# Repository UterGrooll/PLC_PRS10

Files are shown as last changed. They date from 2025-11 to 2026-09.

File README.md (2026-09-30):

# PLC_PRS10

ПЛК ПРС-10 на Arduino + Ethernet. Использую для своих задач в Rapid SCADA: два реле, местный датчик DS18B20 и четыре дискретных входа.

Обмен — `Modbus TCP Slave`, библиотека [ModbusTCP_RU](https://github.com/UterGrooll/ModbusTCP_RU) `0.3.0`, Ethernet `W5100/W5500`.

Фото устройства

## Возможности

- Управление двумя реле из SCADA.
- Автоматическое отключение первого реле через 60 секунд.
- Чтение температуры DS18B20 с точностью передачи 0,1 °C.
- Четыре дискретных входа с антидребезгом 50 мс.
- Восстановление Modbus-сервера после возврата Ethernet-линка W5500.

## Аппаратная часть

| Узел | Пин Arduino |
| --- | --- |
| Реле 1 | D7 |
| Реле 2 | D6 |
| DI1 | D2 |
| DI2 | D3 |
| DI3 | D4 |
| DI4 | D5 |
| DS18B20 | D9 |
| W5100/W5500 CS | D10 |

Реле включаются уровнем `HIGH`, при запуске оба выключены (`LOW`). Входы работают через `INPUT_PULLUP`: замкнутый на GND контакт — активный вход.

Ethernet использует стандартные пины SPI платы.

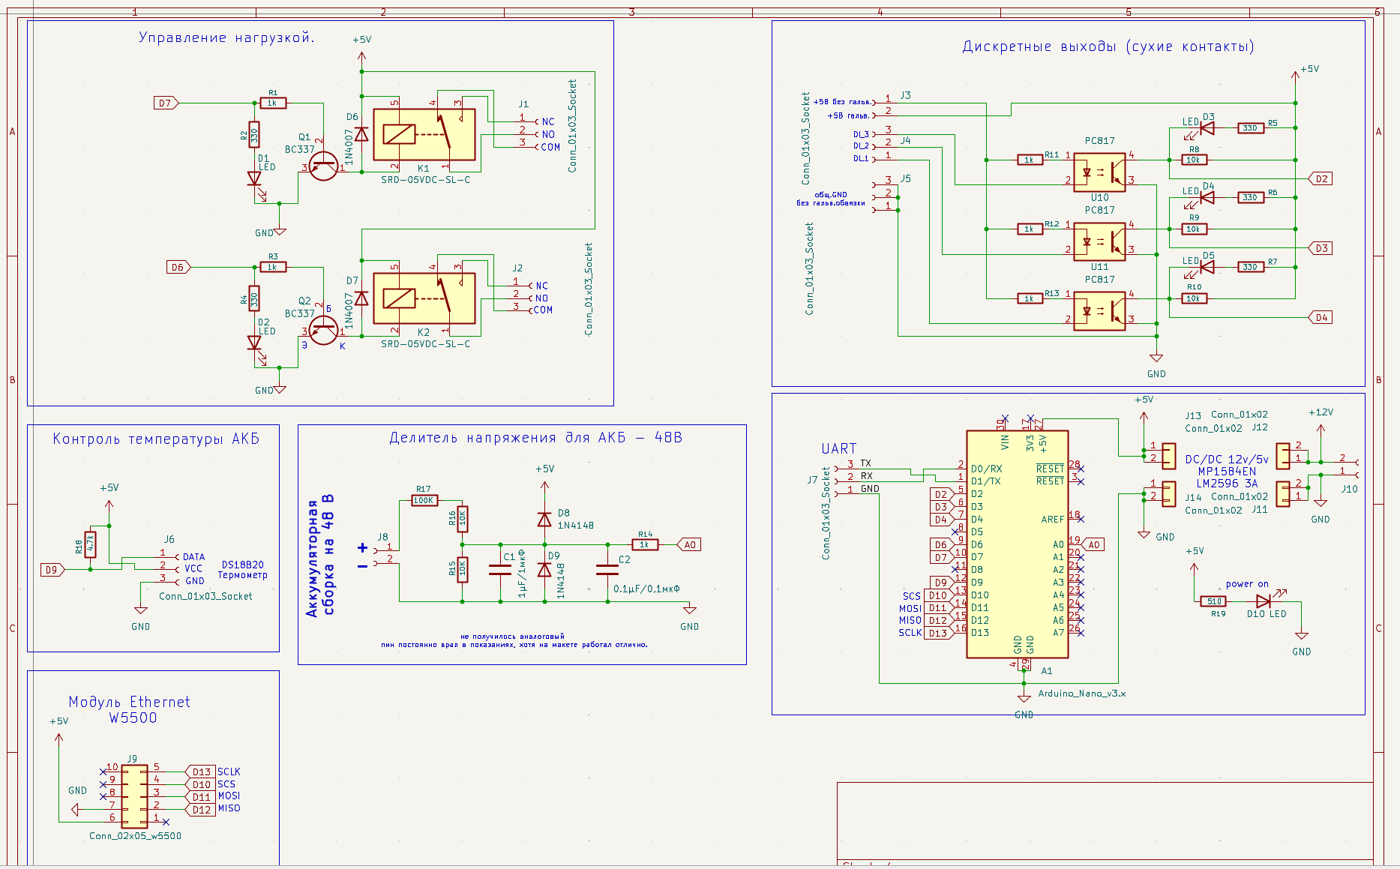
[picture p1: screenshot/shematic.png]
Схема


## Сеть

| Параметр | Значение |
| --- | --- |
| IP | `192.168.1.179` |
| MAC | `02:47:A1:10:00:02` |
| Шлюз / DNS | `192.168.1.1` |
| Маска | `255.255.255.0` |
| Порт Modbus TCP | `502` |

Для проверки нужен доступ к сети `192.168.1.0/24`. При необходимости сетевые параметры меняются в начале скетча. MAC и IP не должны совпадать с другим устройством в сети.

## Карта Modbus

Адреса в таблице начинаются с нуля. Coils, Discrete Inputs и Input Registers — отдельные области памяти.

| Область | FC | Address | Назначение |
| --- | --- | --- | --- |
| Coil | 01 / 05 / 15 | 0 | Реле 1, D7; авто-отключение через 60 с |
| Coil | 01 / 05 / 15 | 1 | Реле 2, D6 |
| Discrete Input | 02 | 0 | DI1, D2 |
| Discrete Input | 02 | 1 | DI2, D3 |
| Discrete Input | 02 | 2 | DI3, D4 |
| Discrete Input | 02 | 3 | DI4, D5 |
| Input Register | 04 | 0 | Местная температура DS18B20, °C × 10 |

Для реле: `0 = OFF`, `1 = ON`. Повторная команда ON не продлевает таймер реле 1; для нового цикла нужны OFF → ON. Время задаётся константой `RELAY1_TIMEOUT` в скетче. Настройки времени через Holding Registers здесь нет.

Для входов: `1 = замкнут / LOW`, `0 = разомкнут / HIGH`.

Температура передаётся как **Signed 16-bit**: `253 = 25,3 °C`, `-55 = -5,5 °C`. Значение `32767` означает ошибку или отсутствие измерения; его нельзя пересчитывать в температуру.

## Настройка Modbus Poll

Connection → Connect:

| Параметр | Значение |
| --- | --- |
| Connection | Modbus TCP/IP |
| IP | `192.168.1.179` |
| Server Port | `502` |
| Slave ID | `1` |
| Response Timeout | `1000 ms` |

Read/Write Definition:

| Что читать | Function | Address | Quantity |
| --- | --- | --- | --- |
| Реле | 01 Read Coils | 0 | 2 |
| Входы | 02 Read Discrete Inputs | 0 | 4 |
| Температура | 04 Read Input Registers | 0 | 1 |

Scan Rate для начала — `1000 ms`. При вводе этих адресов отключить `PLC Addresses (Base 1)`.

Запись реле выполняется через `05 Write Single Coil`: Address `0` для первого реле или `1` для второго, Value `ON/OFF`. Команду записи отправлять однократно.

Для температуры выбрать Signed 16-bit и делить значение на 10 в SCADA.

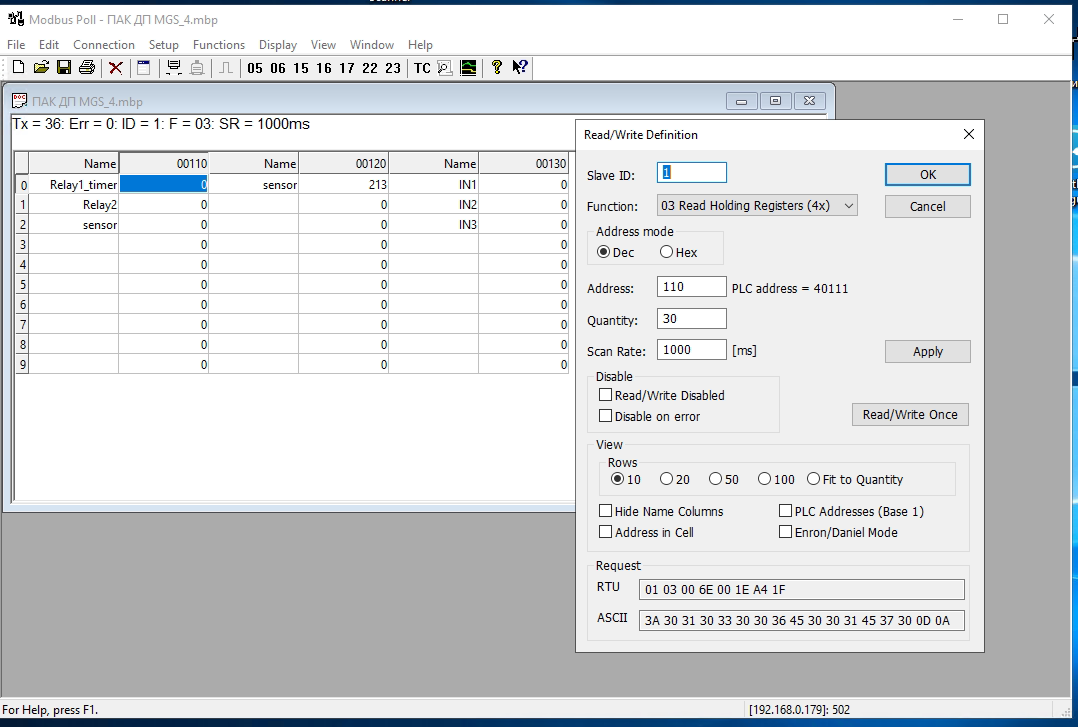
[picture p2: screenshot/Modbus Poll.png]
Modbus Poll


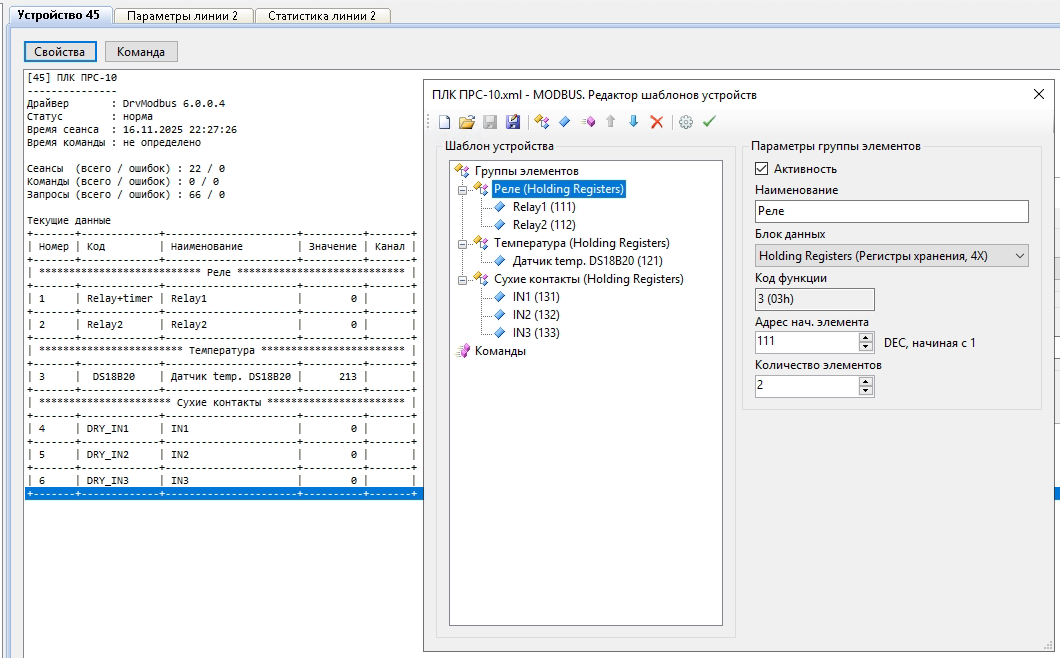
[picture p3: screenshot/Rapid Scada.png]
Rapid SCADA


## Восстановление Ethernet

При старте вызываются `Ethernet.begin(mac, ip, dnsServer, gateway, subnet)` и `mb.begin()`.

После пропадания и устойчивого возврата `LinkON` на W5500 выдерживается не менее 1,5 с, затем `mb.restart()` закрывает старые клиентские соединения. Повторного `Ethernet.begin()` и блокирующей паузы в этом обработчике нет. SCADA или Modbus Poll должны подключиться заново.

W5100 может возвращать `Unknown` в `linkStatus()`. Это не вызывает периодического сброса Ethernet.

Это контроль Ethernet-соединения, **не аппаратный watchdog AVR**. Аппаратный watchdog в этом скетче не включён.

## Прошивка

Актуальный скетч: [firmware/plc_prs10/plc_prs10.ino](firmware/plc_prs10/plc_prs10.ino).

Зависимости:

- `SPI` — входит в Arduino core.
- `Ethernet 2.0.2`.
- [ModbusTCP_RU 0.3.0](https://github.com/UterGrooll/ModbusTCP_RU).
- `GyverDS18`.

Размеры памяти Modbus задаются в общем файле библиотеки `src/ModbusTCP_RU_config.h`, а не через локальные `#define` в скетче.

Скетч собран для Arduino UNO и Nano ATmega328P Old Bootloader: `16820` байт Flash, `771` байт SRAM. Проверка сборки не заменяет испытания этой версии на плате.

После заливки проверить реле, четыре входа, температуру, авто-отключение реле 1 и переподключение после возврата кабеля. Реле проверять на безопасной нагрузке.

## Материалы

- [schematic/](schematic/) — исходники схемы.
- [case/](case/) — модель корпуса.
- [screenshot/](screenshot/) — фотографии и изображения.
- [src/](src/) — предыдущие скетчи; для текущей заливки используется только `firmware/plc_prs10/`.

---

by UterGrooll
2026

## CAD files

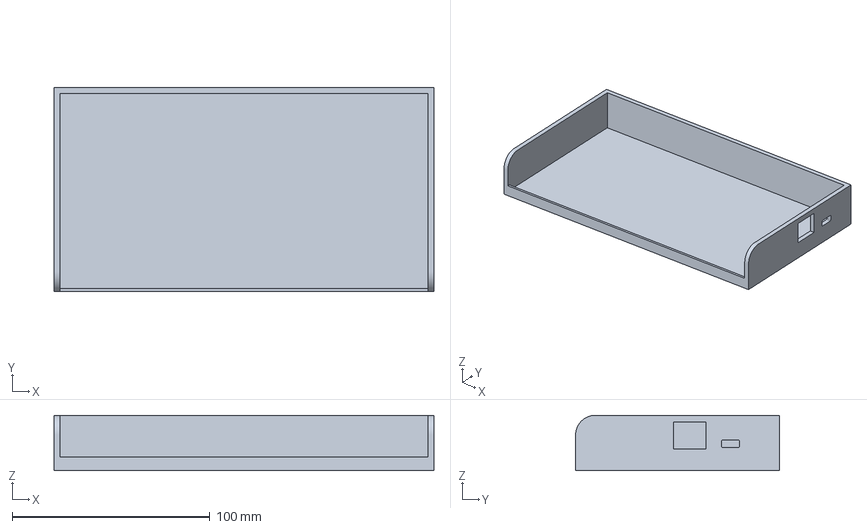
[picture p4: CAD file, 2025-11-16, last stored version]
case/case-Body.3mf
192.0 x 103.0 x 28.0 mm

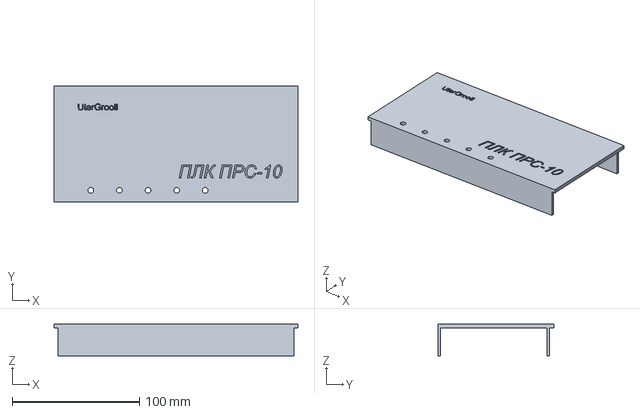
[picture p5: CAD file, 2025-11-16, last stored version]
case/case-ТелоPocket004.3mf
192.0 x 91.0 x 25.0 mm

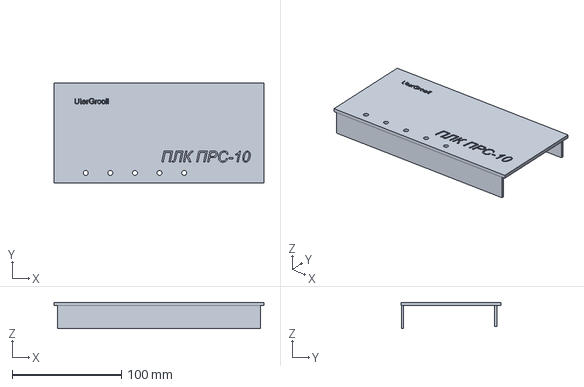
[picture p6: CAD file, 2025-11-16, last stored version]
case/case.FCStd
192.0 x 91.0 x 24.0 mm

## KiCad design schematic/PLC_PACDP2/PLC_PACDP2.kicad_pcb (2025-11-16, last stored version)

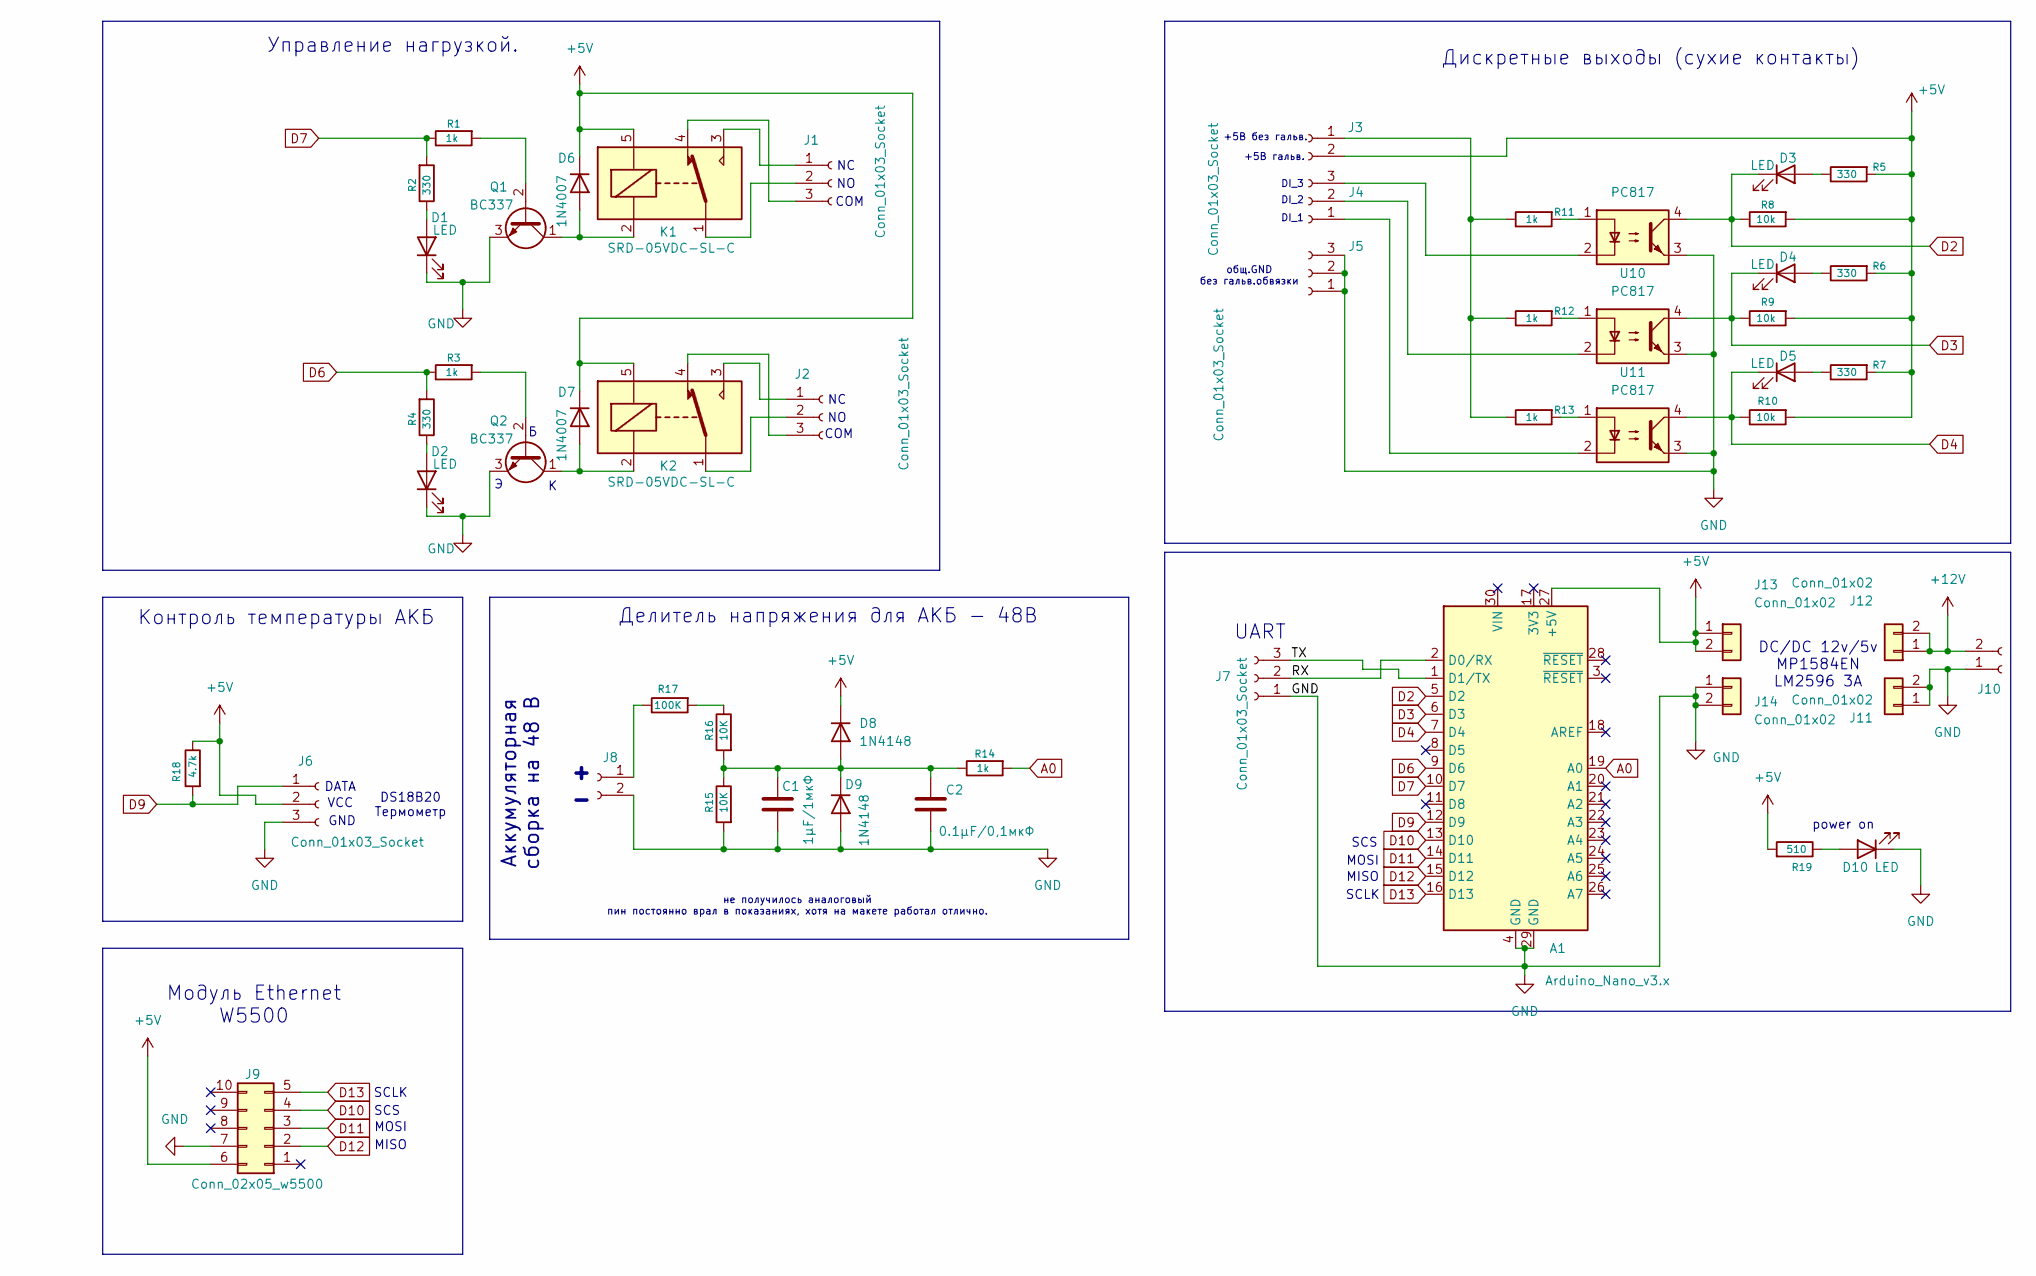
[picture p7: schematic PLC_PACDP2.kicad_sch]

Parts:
A1: Arduino_Nano_v3.x; Arduino_Nano
C1: 1µF/1мкФ; C_Rect_L4.6mm_W2.0mm_P2.50mm_MKS02_FKP02
C2: 0.1µF/0,1мкФ; C_Disc_D7.5mm_W2.5mm_P5.00mm
D1, D2, D3, D4, D5, D10: LED; LED_D5.0mm_Clear
D6, D7: 1N4007; D_DO-41_SOD81_P10.16mm_Horizontal
D8, D9: 1N4148; D_DO-35_SOD27_P7.62mm_Horizontal
J1, J2, J4, J5, J6: Conn_01x03_Socket; TerminalBlock_Phoenix_MKDS-1,5-3-5.08_1x03_P5.08mm_Horizont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
J3, J10: Conn_01x02_Socket; TerminalBlock_Phoenix_MKDS-1,5-2-5.08_1x02_P5.08mm_Horizont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; PartNumber KLS2-128-5.00-02P-4S
J7: Conn_01x03_Socket; PinSocket_1x03_P2.54mm_Vertical
J8: Conn_01x02_Socket; TerminalBlock_MetzConnect_Type703_RT10N02HGLU_1x02_P9.52mm_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; PartNumber KLS2-128-5.00-02P-4S
J9: Conn_02x05_w5500; PinSocket_2x05_P2.54mm_Vertical
J11, J12, J13, J14: Conn_01x02; PinSocket_1x02_P2.54mm_Vertical
K1, K2: SRD-05VDC-SL-C; Relay_SPDT_SANYOU_SRD_Series_Form_C
Q1, Q2: BC337; TO-92_Inline
R1, R3, R11, R12, R13, R14: 1k; R_Axial_DIN0207_L6.3mm_D2.5mm_P10.16mm_Horizontal; PartNumber RC0805FR-07510RL
R2, R4, R5, R6, R7: 330; R_Axial_DIN0207_L6.3mm_D2.5mm_P10.16mm_Horizontal; PartNumber RC0805FR-07510RL
R8, R9, R10: 10k; R_Axial_DIN0207_L6.3mm_D2.5mm_P10.16mm_Horizontal; PartNumber RC0805FR-07510RL
R15, R16: 10K; R_Axial_DIN0207_L6.3mm_D2.5mm_P10.16mm_Horizontal; PartNumber RC0805FR-07510RL
R17: 100K; R_Axial_DIN0207_L6.3mm_D2.5mm_P10.16mm_Horizontal; PartNumber RC0805FR-07510RL
R18: 4.7k; R_Axial_DIN0207_L6.3mm_D2.5mm_P10.16mm_Horizontal; PartNumber RC0805FR-07510RL
R19: 510; R_Axial_DIN0207_L6.3mm_D2.5mm_P10.16mm_Horizontal; PartNumber RC0805FR-07510RL
U9, U10, U11: PC817; DIP-4_W7.62mm

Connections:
+5V: A1.27 (+5V), D6.1 (K), D7.1 (K), D8.1 (K), J3.2, J6.2, J9.6 (+5), J13.1, J13.2, K1.5, K2.5, R5.2, R6.2, R7.2, R8.2, R9.2, R10.2, R18.1, R19.2
+12V: J10.2, J12.1, J12.2
/RX: A1.2 (D0/RX), J7.2
/TX: A1.1 (D1/TX), J7.3
D2: A1.5 (D2), D3.1 (K), R8.1, U9.4
D3: A1.6 (D3), D4.1 (K), R9.1, U10.4
D4: A1.7 (D4), D5.1 (K), R10.1, U11.4
D6: A1.9 (D6), R3.1, R4.2
D7: A1.10 (D7), R1.1, R2.2
D9: A1.12 (D9), J6.1, R18.2
D10: A1.13 (D10), J9.4 (SCS)
D11: A1.14 (D11), J9.3 (MOSI)
D12: A1.15 (D12), J9.2 (MISO)
D13: A1.16 (D13), J9.5 (SCLK)
GND: A1.4 (GND), A1.29 (GND), C1.2, C2.2, D1.1 (K), D2.1 (K), D9.2 (A), D10.1 (K), J5.1, J5.2, J5.3, J6.3, J7.1, J8.2, J9.7 (GND), J10.1, J11.1, J11.2, J14.1, J14.2, Q1.3 (E), Q2.3 (E), R15.2, U9.3, U10.3, U11.3
unnamed: D1.2 (A), R2.1
unnamed: D2.2 (A), R4.1
unnamed: D3.2 (A), R5.1
unnamed: D4.2 (A), R6.1
unnamed: D5.2 (A), R7.1
unnamed: D6.2 (A), K1.2, Q1.1 (C)
unnamed: D7.2 (A), K2.2, Q2.1 (C)
unnamed: C1.1, C2.1, D8.2 (A), D9.1 (K), R14.1, R15.1, R16.2
unnamed: D10.2 (A), R19.1
unnamed: J1.1, K1.3
unnamed: J1.2, K1.1
unnamed: J1.3, K1.4
unnamed: J2.1, K2.3
unnamed: J2.2, K2.1
unnamed: J2.3, K2.4
unnamed: J3.1, R11.1, R12.1, R13.1
unnamed: J4.1, U11.2
unnamed: J4.2, U10.2
unnamed: J4.3, U9.2
unnamed: J8.1, R17.1
unnamed: Q1.2 (B), R1.2
unnamed: Q2.2 (B), R3.2
unnamed: R11.2, U9.1
unnamed: R12.2, U10.1
unnamed: R13.2, U11.1
unnamed: R16.1, R17.2
А0: A1.19 (A0), R14.2

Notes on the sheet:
Управление нагрузкой.
SCS
DI_3
DI_2
Аккумуляторная сборка на 48 В
Модуль Ethernet W5500
COM
UART
SCLK
DS18B20 Термометр
DATA
MOSI
VCC
Контроль температуры АКБ
GND
MISO
общ.GND без гальв.обвязки
+5В гальв.
DC/DC 12v/5v MP1584EN LM2596 3A
DI_1
+5В без гальв.
power on
не получилось аналоговый пин постоянно врал в показаниях, хотя на макете работал отлично.
Дискретные выходы (сухие контакты)
Делитель напряжения для АКБ - 48В

Board: 2 copper layers, 53 parts (0 on the bottom side), 42 nets, no tracks yet.

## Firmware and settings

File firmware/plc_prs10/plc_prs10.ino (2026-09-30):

#include <SPI.h>
#include <Ethernet.h>
#include "ModbusTCP_RU.h"
#include <GyverDS18.h>

/* ---------- Network & Modbus ---------- */
byte mac[] = {0x02, 0x47, 0xA1, 0x10, 0x00, 0x02};
IPAddress ip(192, 168, 1, 179);
IPAddress gateway(192, 168, 1, 1);
IPAddress dnsServer(192, 168, 1, 1);
IPAddress subnet(255, 255, 255, 0);

ModbusTCP_RU mb;

/* ---------- Relays: Coils, FC01/FC05/FC15 ---------- */
const uint8_t RELAY1_PIN = 7;
const uint8_t RELAY2_PIN = 6;

const word COIL_RELAY1 = 0;
const word COIL_RELAY2 = 1;

const uint32_t RELAY1_TIMEOUT = 60000UL;  // 1 min
uint32_t relay1OnTime = 0;
bool relay1Active = false;

/* ---------- Temperature: Input Register, FC04 ---------- */
const uint8_t DS_PIN = 9;
GyverDS18Single ds(DS_PIN);

const word IREG_TEMP_X10 = 0;  // temperature * 10
const int16_t TEMP_ERROR_X10 = 32767;  // invalid/unavailable, not a temperature
const uint32_t TEMP_PERIOD_MS = 1000UL;  // >= 750 ms conversion at 12 bits
uint32_t temperatureRequestTime = 0;
bool temperatureConversionPending = false;

/* ---------- Inputs: Discrete Inputs, FC02 ---------- */
const uint8_t IN_PINS[] = { 2, 3, 4, 5 };
const uint8_t INPUT_COUNT = sizeof(IN_PINS) / sizeof(IN_PINS[0]);

const word DISC_INPUT_BASE = 0;

const uint32_t DEBOUNCE_MS = 50;
uint8_t inputState = 0;
uint8_t inputLast = 0;
uint32_t debounceTimer = 0;

/* ---------- Ethernet watchdog ---------- */
const uint32_t LINK_CHECK_PERIOD_MS = 1000UL;
const uint32_t LINK_RECOVER_DELAY_MS = 1500UL;

uint32_t linkCheckTimer = 0;
uint32_t linkUpTime = 0;
bool linkWasDown = false;
bool linkRecovering = false;

static_assert(MB_MAX_COILS > COIL_RELAY2, "Coil map is too small");
static_assert(MB_MAX_DISCRETE >= DISC_INPUT_BASE + INPUT_COUNT, "Discrete map is too small");
static_assert(MB_MAX_INPUT > IREG_TEMP_X10, "Input register map is too small");

void startEthernet()
{
  Ethernet.begin(mac, ip, dnsServer, gateway, subnet);
  mb.begin();
}

void updateEthernetWatchdog()
{
  uint32_t now = millis();

  if (now - linkCheckTimer < LINK_CHECK_PERIOD_MS) {
    return;
  }
  linkCheckTimer = now;

  EthernetLinkStatus link = Ethernet.linkStatus();

  if (link == LinkOFF) {
    linkWasDown = true;
    linkRecovering = false;
    return;
  }

  // W5100 reports Unknown; do not periodically reset an otherwise working chip.
  if (link == Unknown) {
    linkRecovering = false;
    return;
  }

  if (link == LinkON && linkWasDown) {
    if (!linkRecovering) {
      linkRecovering = true;
      linkUpTime = now;
    }
    if (now - linkUpTime >= LINK_RECOVER_DELAY_MS) {
      linkWasDown = false;
      linkRecovering = false;
      mb.restart();
    }
  }
}

void applyRelay(word address, bool value)
{
  switch (address) {
    case COIL_RELAY1:
      // Repeated SCADA writes must not postpone automatic shutdown.
      if (value && !relay1Active) {
        relay1OnTime = millis();
      } else if (!value) {
        relay1OnTime = 0;
      }
      relay1Active = value;
      digitalWrite(RELAY1_PIN, value ? HIGH : LOW);
      break;

    case COIL_RELAY2:
      digitalWrite(RELAY2_PIN, value ? HIGH : LOW);
      break;
  }
}

uint8_t readInputsRaw()
{
  uint8_t value = 0;

  for (uint8_t i = 0; i < INPUT_COUNT; i++) {
    if (digitalRead(IN_PINS[i]) == LOW) {
      value |= (1 << i);
    }
  }

  return value;
}

void updateInputs(uint32_t now)
{
  uint8_t nowInputs = readInputsRaw();

  if (nowInputs != inputLast) {
    inputLast = nowInputs;
    debounceTimer = now;
    return;
  }

  if ((now - debounceTimer) >= DEBOUNCE_MS && nowInputs != inputState) {
    inputState = nowInputs;

    for (uint8_t i = 0; i < INPUT_COUNT; i++) {
      mb.Discrete(DISC_INPUT_BASE + i, (inputState >> i) & 1);
    }
  }
}

void updateRelayTimer(uint32_t now)
{
  if (relay1Active && (uint32_t)(now - relay1OnTime) >= RELAY1_TIMEOUT) {
    mb.setCoilLocal(COIL_RELAY1, false);
    applyRelay(COIL_RELAY1, false);
  }
}

void startTemperatureConversion()
{
  temperatureConversionPending = ds.requestTemp();
  temperatureRequestTime = millis();
  if (!temperatureConversionPending) {
    mb.Ireg(IREG_TEMP_X10, (word)TEMP_ERROR_X10);
  }
}

void updateTemperature()
{
  // Independent timer: a failed request must not prevent the next retry.
  if ((uint32_t)(millis() - temperatureRequestTime) < TEMP_PERIOD_MS) {
    return;
  }

  if (temperatureConversionPending && ds.readTemp()) {
    float temperature = ds.getTemp();
    int16_t tempX10 = (int16_t)(temperature * 10.0f);
    mb.Ireg(IREG_TEMP_X10, (word)tempX10);
  } else {
    mb.Ireg(IREG_TEMP_X10, (word)TEMP_ERROR_X10);
  }

  startTemperatureConversion();
}

void setup()
{
  pinMode(RELAY1_PIN, OUTPUT);
  pinMode(RELAY2_PIN, OUTPUT);

  digitalWrite(RELAY1_PIN, LOW);
  digitalWrite(RELAY2_PIN, LOW);

  mb.setCoilLocal(COIL_RELAY1, false);
  mb.setCoilLocal(COIL_RELAY2, false);
  mb.Ireg(IREG_TEMP_X10, (word)TEMP_ERROR_X10);

  for (uint8_t i = 0; i < INPUT_COUNT; i++) {
    pinMode(IN_PINS[i], INPUT_PULLUP);
    mb.Discrete(DISC_INPUT_BASE + i, false);
  }

  inputState = readInputsRaw();
  inputLast = inputState;

  for (uint8_t i = 0; i < INPUT_COUNT; i++) {
    mb.Discrete(DISC_INPUT_BASE + i, (inputState >> i) & 1);
  }

  mb.onCoilWrite(applyRelay);

  Ethernet.init(10);
  startEthernet();

  startTemperatureConversion();
}

void loop()
{
  mb.MbsRun();

  uint32_t now = millis();
  updateRelayTimer(now);
  updateEthernetWatchdog();
  updateTemperature();
  updateInputs(now);
}

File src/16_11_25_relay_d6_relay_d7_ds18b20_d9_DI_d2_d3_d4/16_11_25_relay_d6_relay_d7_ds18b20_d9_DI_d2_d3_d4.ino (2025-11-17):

#include <SPI.h>
#include <Ethernet.h>
#include <ModbusEthernet.h>
#include <GyverDS18.h>

/* ---------- Network & Modbus ---------- */
byte mac[] = { 0xDE, 0xDD, 0xBE, 0xEF, 0xFE, 0x01 };
IPAddress ip(192, 168, 0, 179);
ModbusEthernet mb;

/* ---------- Relays ---------- */
const uint8_t RELAY1_PIN = 7;
const uint8_t RELAY2_PIN = 6;
const uint16_t REG_RELAY1 = 110;
const uint16_t REG_RELAY2 = 111;
const uint32_t RELAY1_TIMEOUT = 60000UL;  // 1 min
uint32_t relay1OnTime = 0;

/* ---------- Temperature ---------- */
const uint8_t DS_PIN = 9;
GyverDS18Single ds(DS_PIN);
const uint16_t REG_TEMP = 120;

/* ---------- Inputs ---------- */
const uint8_t IN_PINS[] = { 2, 3, 4, 5 };
const uint16_t REG_IN_BASE = 130;
const uint32_t DEBOUNCE_MS = 50;
uint8_t inputState = 0xFF;  // 1=closed (LOW), 0=open (HIGH)
uint8_t inputLast  = 0xFF;
uint32_t debounceTimer = 0;

/* ---------- Serial debug ---------- */
uint32_t serialTimer = 0;
const uint32_t SERIAL_PERIOD = 500;

/* ---------- Setup ---------- */
void setup() {
  Serial.begin(115200);
  pinMode(RELAY1_PIN, OUTPUT);
  pinMode(RELAY2_PIN, OUTPUT);
  digitalWrite(RELAY1_PIN, LOW);
  digitalWrite(RELAY2_PIN, LOW);

  for (uint8_t i = 0; i < 4; ++i) {
    pinMode(IN_PINS[i], INPUT_PULLUP);
    mb.addReg(HREG(REG_IN_BASE + i));
    mb.Hreg(REG_IN_BASE + i, 0);
  }

  Ethernet.init(10);
  Ethernet.begin(mac, ip);
  mb.server();

  mb.addReg(HREG(REG_RELAY1));
  mb.Hreg(REG_RELAY1, 0);
  mb.addReg(HREG(REG_RELAY2));
  mb.Hreg(REG_RELAY2, 0);
  mb.addReg(HREG(REG_TEMP));
  mb.Hreg(REG_TEMP, 0);

  ds.requestTemp();

  Serial.println(F("System Ready!"));
}

/* ---------- Main loop ---------- */
void loop() {
  mb.task();  // handle Modbus requests
  uint32_t now = millis();

  /* ===== Relay 1 with timer ===== */
  if (mb.Hreg(REG_RELAY1)) {
    digitalWrite(RELAY1_PIN, HIGH);
    if (!relay1OnTime) relay1OnTime = now;
    if ((now - relay1OnTime) >= RELAY1_TIMEOUT) {
      mb.Hreg(REG_RELAY1, 0);
      relay1OnTime = 0;
      digitalWrite(RELAY1_PIN, LOW);
    }
  } else {
    relay1OnTime = 0;
    digitalWrite(RELAY1_PIN, LOW);
  }

  /* ===== Relay 2 ===== */
  digitalWrite(RELAY2_PIN, mb.Hreg(REG_RELAY2) ? HIGH : LOW);

  /* ===== Temperature ===== */
  if (ds.ready()) {
    if (ds.readTemp()) {
      float t = ds.getTemp();
      mb.Hreg(REG_TEMP, (int)(t * 10));  // 1/10 °C precision
    }
    ds.requestTemp();  // schedule next reading
  }

  /* ===== Dry contacts with debounce ===== */
  uint8_t nowInputs = 0;
  for (uint8_t i = 0; i < 4; ++i) {
    if (digitalRead(IN_PINS[i]) == LOW) nowInputs |= (1 << i);
  }

  if (nowInputs != inputLast) {
    debounceTimer = now;
    inputLast = nowInputs;
  } else if ((now - debounceTimer) >= DEBOUNCE_MS && nowInputs != inputState) {
    inputState = nowInputs;
    for (uint8_t i = 0; i < 4; ++i) {
      mb.Hreg(REG_IN_BASE + i, (inputState >> i) & 1);
    }
  }

  /* ===== Serial debug (non‑blocking) ===== */
  if ((now - serialTimer) >= SERIAL_PERIOD) {
    serialTimer = now;
    Serial.print(F("Temp="));
    Serial.print(mb.Hreg(REG_TEMP) / 10.0);
    Serial.print(F("C R1="));
    Serial.print(mb.Hreg(REG_RELAY1));
    Serial.print(F(" R2="));
    Serial.print(mb.Hreg(REG_RELAY2));
    Serial.print(F(" IN="));
    Serial.println(inputState, BIN);
  }
}

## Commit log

2025-11-16 Create README.md
    описание
2026-09-30 Update PLC_PRS10 firmware for ModbusTCP_RU 0.3.0 without UART receiver
